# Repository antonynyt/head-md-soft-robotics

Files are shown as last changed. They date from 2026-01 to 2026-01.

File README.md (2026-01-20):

# Pulmo

**Pulmo** is a speculative robot inspired by sea slugs and bioluminescent marine life. It performs slow, breathing-like movements. As air pollution increases, Pulmo’s breathing becomes rapid. Its skin shifts to red as a warning signal. In clean air, its breathing is slow and its body emits a blue-green glow. Pulmo makes air pollution visible and emotionally perceptible.

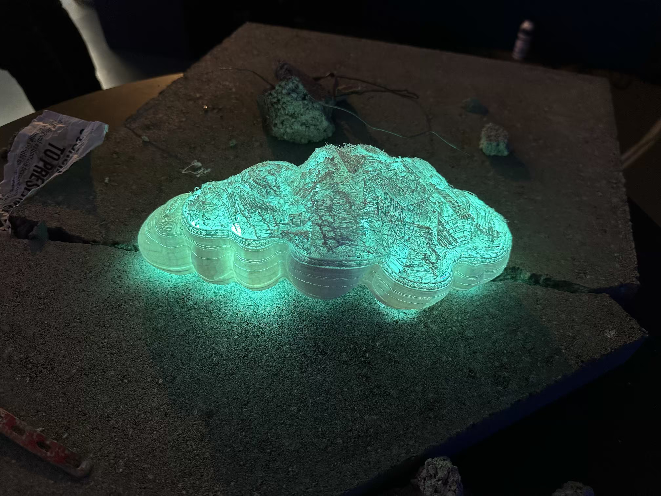
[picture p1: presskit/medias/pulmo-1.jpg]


Pulmo is part of a fictional group of robots created by the last humans before all living beings on Earth had disappeared. These robots were meant to care for the planet, based on the belief that technology could fix the damage humans had caused. Long after humans are gone, the robots continue their work alone making them useless creatures.

## Components

This project is a mix of Arduino & 3D printing. It uses one servo-motor, a CO2 sensor MQ-135 and LEDs ([see details](code)).

# What’s in this repo

- [process/journal.md](process/journal.md) — Development journal
- [process/](process) — Project process
- [code/](code) — Arduino code & schematics
- [presskit/](presskit) — Abstract and medias about the project

> *Most of our process is written in french.*

## Team
Vincent Paley [@noctoplasma](https://instagram.com/noctoplasma) & Antony Neyret [antony.cool](https://antony.cool/)

# About the workshop — Soft Robotics

Project made during the Soft Robotics workshop in Master Media Design, HEAD – Genève.

- **Partners: CNRS, CEA, INRIA**
- **Professors: Clara Rigaud, Benjamin Gaulon**

As our planet faces accelerating ecological crises, robotics offers new ways of perceiving, sensing, and interacting with the environment. Moving beyond efficiency and automation, this workshop explores soft, ecological, and sensitive robots.

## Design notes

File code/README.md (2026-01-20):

# Components

- Arduino Uno R3
- MQ-135
- LED 20mm [Adafruit](https://www.adafruit.com/product/1547) [docs](https://learn.adafruit.com/20mm-led-pixels?embeds=allow)
- Basic servo-motor

# Wiring
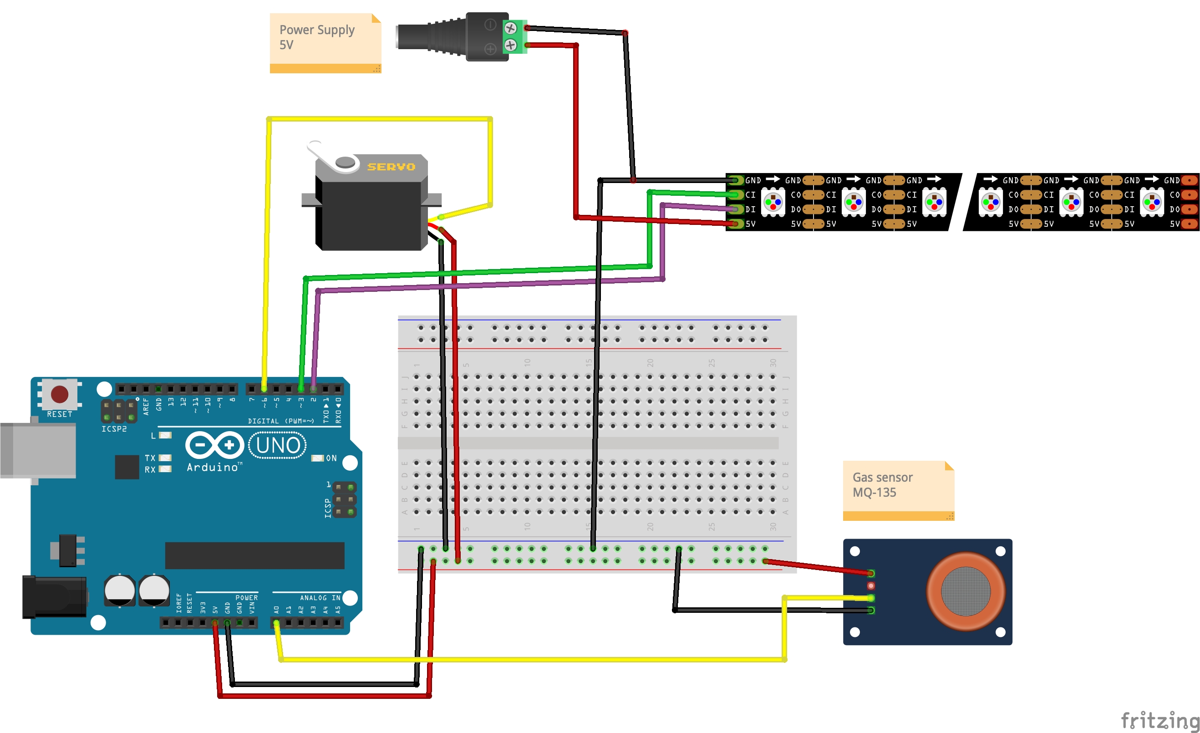
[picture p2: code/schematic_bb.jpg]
[fritzing schematic file](schematic.fzz)

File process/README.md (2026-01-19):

# Process

- [Journal](journal.md)
- [3D Files](3D) - contains `stl` files for 3D printing

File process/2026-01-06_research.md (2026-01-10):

https://www.berndnaut.nl/
bioluminéscence

Télégraphe optique: communication.
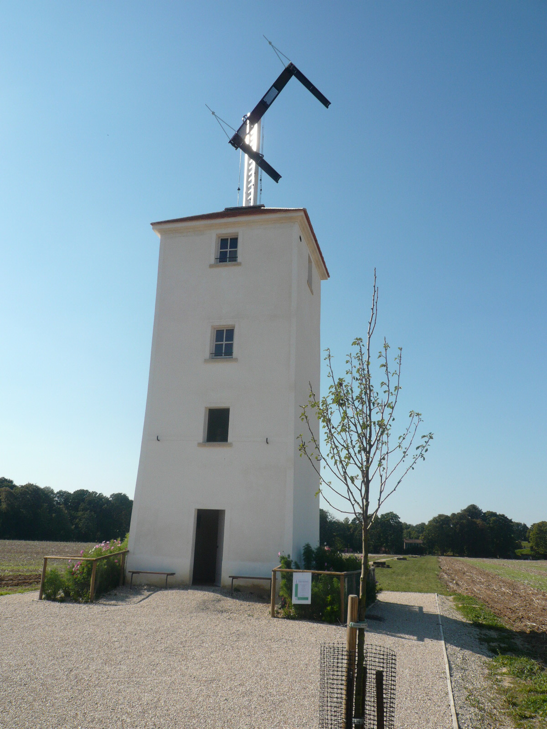
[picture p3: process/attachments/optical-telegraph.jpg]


Mammlus pour la forme jellyfishy
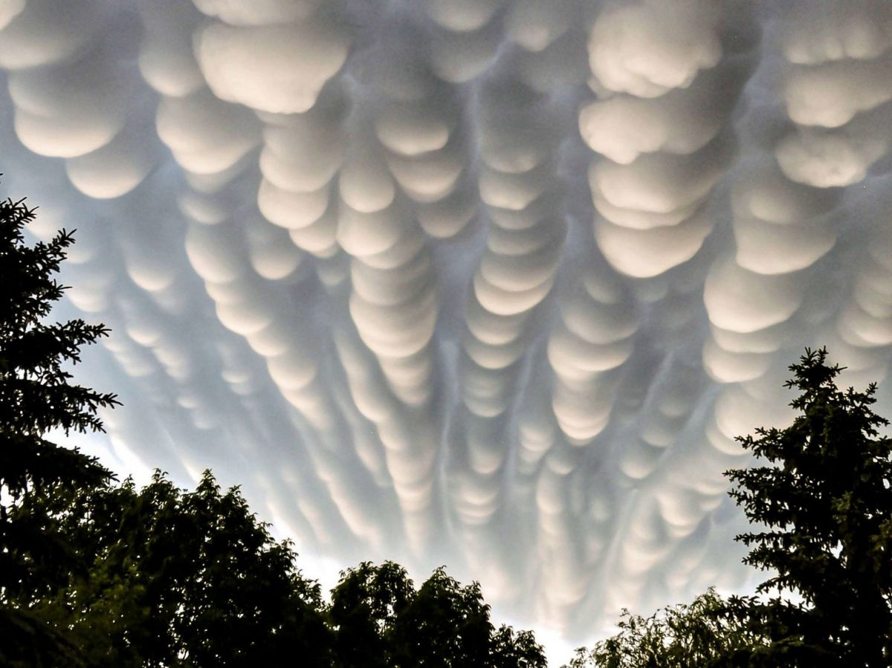
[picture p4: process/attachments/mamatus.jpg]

Omus pour les yeux.
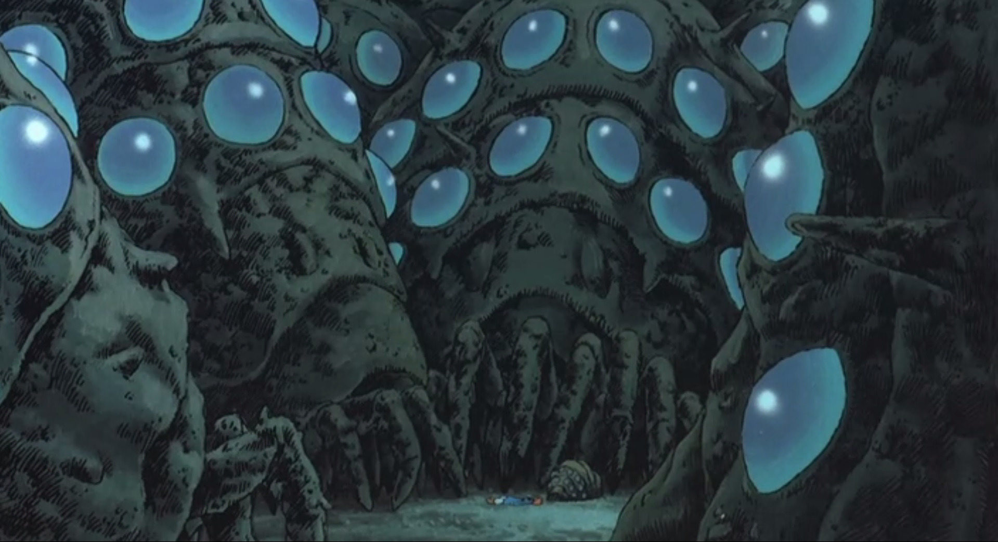
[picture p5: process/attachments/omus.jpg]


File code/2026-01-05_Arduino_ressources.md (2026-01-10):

## Wiki

LED, long leg = +
Diode = one way  -|>-
[Calculer une résistance](https://www.digikey.fr/fr/resources/conversion-calculators/conversion-calculator-resistor-color-code)

## Serial port

[Using the Web Serial API ](https://developer.mozilla.org/en-US/docs/Web/API/Web_Serial_API "https://developer.mozilla.org/en-US/docs/Web/API/Web_Serial_API")
### Sound

https://puredata.info/ -> or max msp, -> create sound
Touch designer
Processing

## 3D - Prototyping

[3D to print dynamic objects](https://news.mit.edu/2025/xstrings-3d-printing-strings-together-dynamic-objects-0318)

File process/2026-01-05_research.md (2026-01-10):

[Seahorse](https://www.youtube.com/watch?v=m7oWvPXz-9c)
[méduses](https://www.arte.tv/fr/videos/120423-000-A/meduses/)
[sponges](https://www.youtube.com/watch?v=pTZ211cIjX8)

# Ideas

inspiré de la fonction des capteurs disponibles.

Air pollution (but [baisse pollution](https://www.rts.ch/meteo/2024/article/impact-paradoxal-de-la-baisse-de-pollution-sur-la-temperature-mondiale-28462833.html))
Air filtering CO2 out.
Water filtering?

Sponge.

Taking care of something makes it evolving.
or a plant controlling you
if you don't take care of it or give it not enough CO2 it shocks you or is evil.

What is the impact on is world ?
Quel est son Umwelt ?

Anémone qui capture: sédentaire
capture l'eau, l'oxygène, co2, transforme, convertir

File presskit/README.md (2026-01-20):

# Pulmo

**Pulmo** is a speculative robot inspired by sea slugs and bioluminescent marine life. It performs slow, breathing-like movements. As air pollution increases, Pulmo’s breathing becomes rapid. Its skin shifts to red as a warning signal. In clean air, its breathing is slow and its body emits a blue-green glow. Pulmo makes air pollution visible and emotionally perceptible. From within its body also escapes a high-pitched, wheezing, almost scream-like noise. As pollution levels rise, this sound intensifies, giving Pulmo a fragile, anxious personality.



Pulmo is part of a fictional group of robots created by the last humans before all living beings on Earth had disappeared. These robots were meant to care for the planet, based on the belief that technology could fix the damage humans had caused. Long after humans are gone, the robots continue their work alone making them useless creatures.

# Process

The project followed an iterative process based on research and experiments. We started with ideas inspired by jellyfish and communication systems, trying to solve many problems at once instead of focusing on one. So, we then shifted to a simpler and more emotional concept. We did field research, took apart old tech, tested light communication and tried different mechanical and 3D-printed prototypes. We learned a lot from mistakes and even got some happy accidents like the 3D TPU printing. This created an **organic, soft, and vulnerable look** for the robot.

# Scenography

|  |  |
| --- | --- |

# References

*Pulmo* is inspired by marine organisms reacting to toxic environments and bioluminescent warning systems.

- **Tobias Bradford – dying mechanical dog**  
- **marine organisms (sea-slugs, jellyfish) when on land**  
- **Bioluminescent sea animals** : Light as a stress signal or defense mechanism
- **Ômu – _Nausicaä of the Valley of the Wind_**  

# Medias

[Link to medias folder](medias) — [Presentation](keynote.pdf)

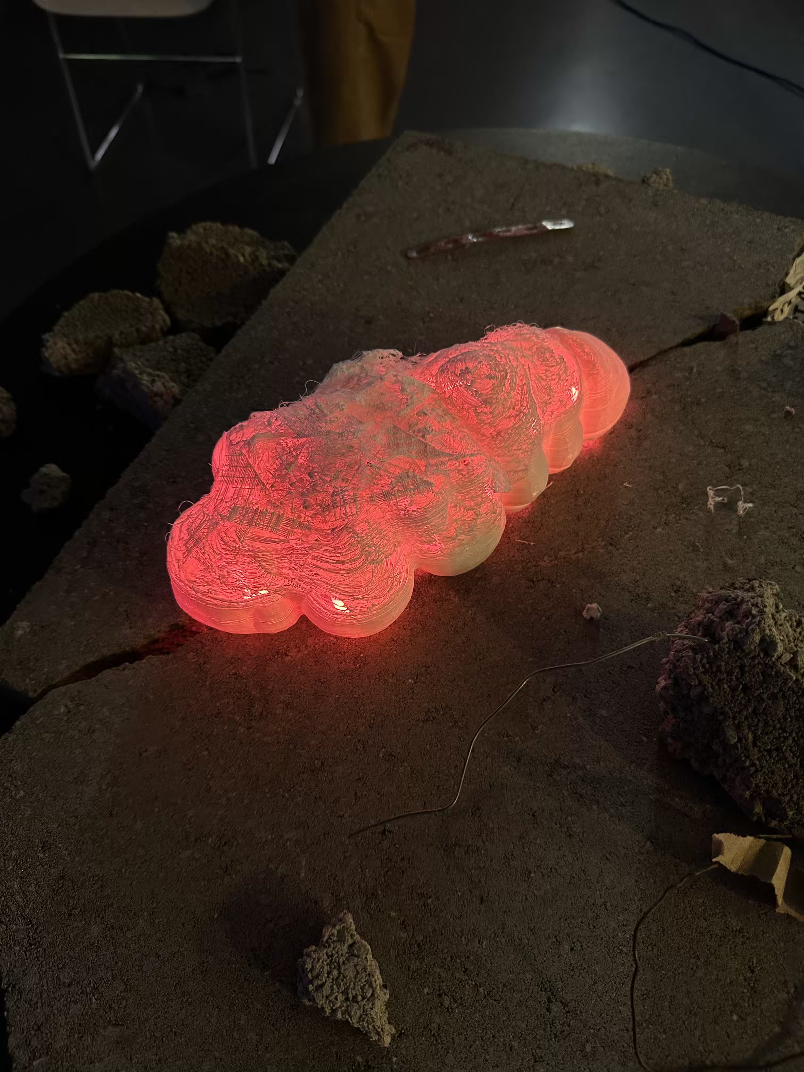
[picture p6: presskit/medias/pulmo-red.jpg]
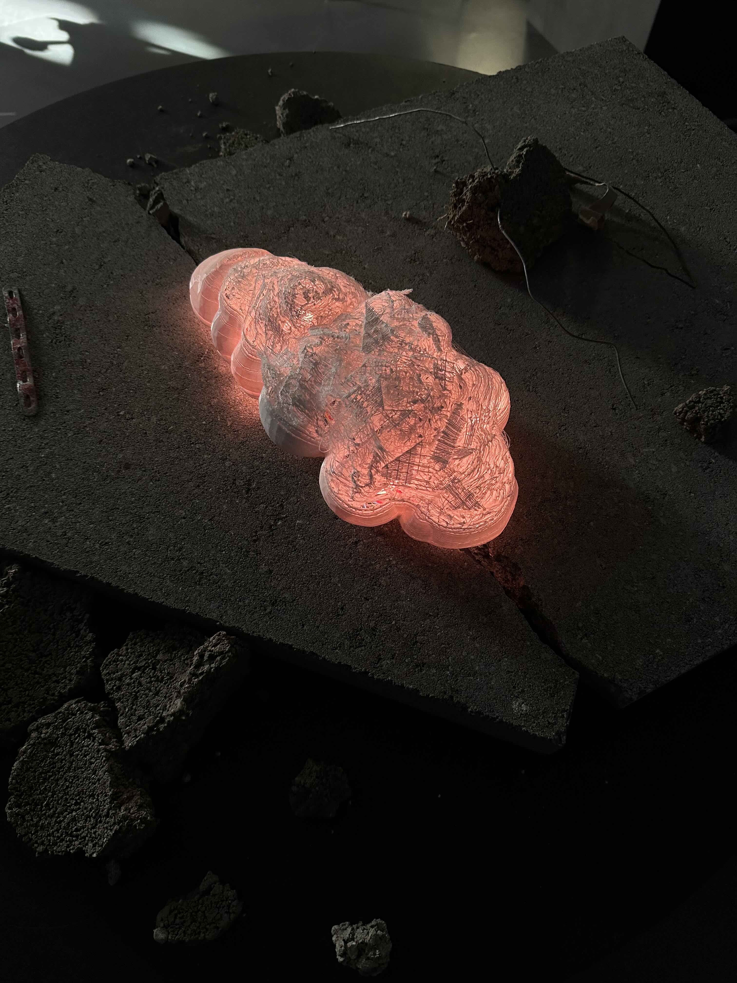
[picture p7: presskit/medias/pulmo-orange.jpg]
|  |  |
| --- | --- |

# Team
Vincent Paley [@noctoplasma](https://instagram.com/noctoplasma) & Antony Neyret [https://antony.cool](https://antony.cool/)

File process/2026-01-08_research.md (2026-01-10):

Humidity sensor (DHT11)
Créer des nuages.
# ideation

**Low tech internet**
Alternative au réseau internet low-tech, auto-sufficient
- mesh-network
## Fonctions
- Savoir comment va l'écosystème ? Permet un état de résonance avec l'environnement.
- Créer de la communication entre humains (connaissance, ).
- Créer de la communication entre autres espèces (laser, radio,)

**What if**
- C'est pas des ondes radios? (eau, brume, lumière, télégraphe optique)
- C'est pas statique?
- ça vole ? -> trop complexe

**Un système de communication qui permet de *résonner* avec l'écosystème.**
Comment ? Pourquoi ?

Le sac ça fait un réseau organique qui est dirigé par les éléments et non par choix.
Un peu comme les animaux marins qui se laissent porter par le vent.
[American Beauty](https://www.dailymotion.com/video/xfy8vo)

## Sac plastique 

Un sac se laisse porter par le vent.

Couleurs des animaux bioluminesents pour camouflage, se cacher des prédateurs humains.
ou alors entrer un message dans l'individu façon: dead-drops ou bouteille à la mer.
Risque de regroupement des sacs tous au même endroit.

Métaphore des déchets de la rue qui voguent: **Fonction d'exploration**: capteur de Co2 urbain mouvant ou détecter les amas de déchets

Pluie de déchets: https://www.youtube.com/watch?v=sdfouAdvav4

Connecté à l'individu: voir l'histoire d'un déchet et se qu'il a vécu.
Lâche un fil, fil d'ariane
Boule western désert.

## Autres idées
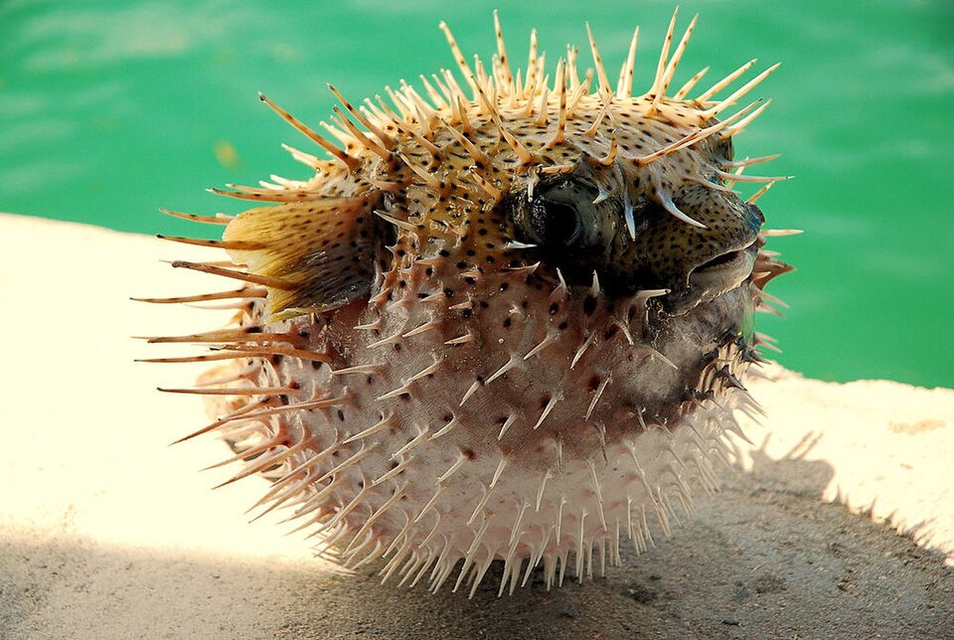
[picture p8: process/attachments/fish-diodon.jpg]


Poisson-hérisson (Diodon)
**Un poisson qui se gonfle comme un ballon en cas de danger.**
- Quel serait ce danger ?

Hippocampe qui s'accroche,
Sauterelle qui saute et plane.

Etoile de mer, qui s'agrippe.
Caméléon.

**--16:43**
Un pont entre l'humain et la nature.
Un pont qui permet de se rendre compte des impact climatiques.
Capteur humidité et CO2.
Cris à l'aide. Buzzer

- define **one precise ecological phenomenon** it translates.
- design **one strong bodily behavior** (instead of many)

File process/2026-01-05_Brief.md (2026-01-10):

HCI human machine interaction
Antropological aspect: what machine that adapt, sense

Maison des humanités potentielles.

what robots wants.
what relationship beyond efficiency.

Marine robotics. the ocean on land
perceving, sensing, interacting with the env.

agents of care and observation

sense humidity, pollution, light
life cycle ecological
fragility, care.
not everything needs to be cute.

Observation des animaux marins.

morphogenesis, 
pattern emerge trough simple chemical processes.

solid <--- viscous --- colloidal --- gel ---> fluid

1. choose non-human reference
2. identify bio mecanisms
3. choose environmental function
4. choose contexte (aquatic, soil, industrial, air, etc.)

filtering -> separate polluants
cleaning -> removing

decompose matter or itself.
plastic operations -> reshape the function, form

1. soft
2. environnemental challenge
3. context
4. function
5. non-human
6. mechanism
7. material
8. operation (plastic)
9. lifecycle
10. interaction
11. energy
12. speculative

it's a proposition not a product.

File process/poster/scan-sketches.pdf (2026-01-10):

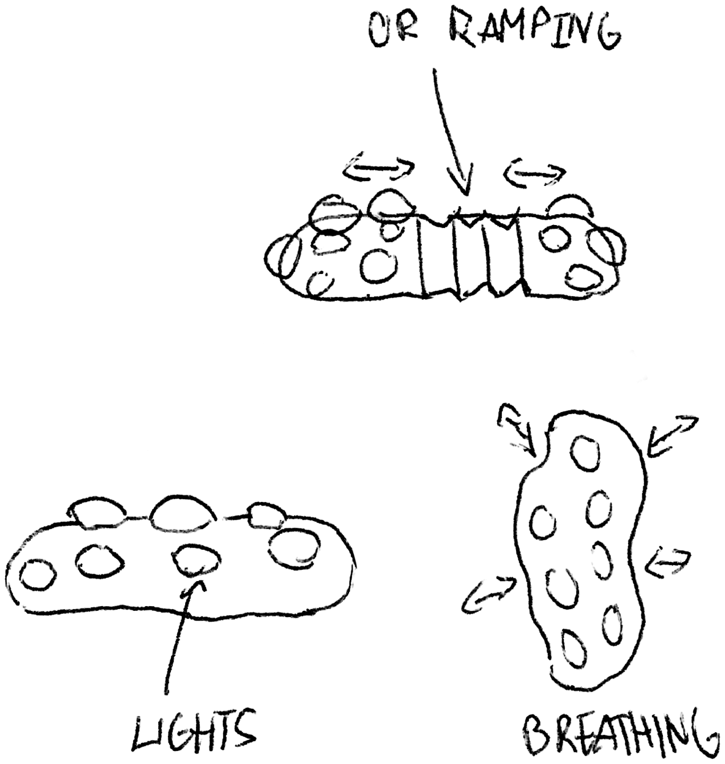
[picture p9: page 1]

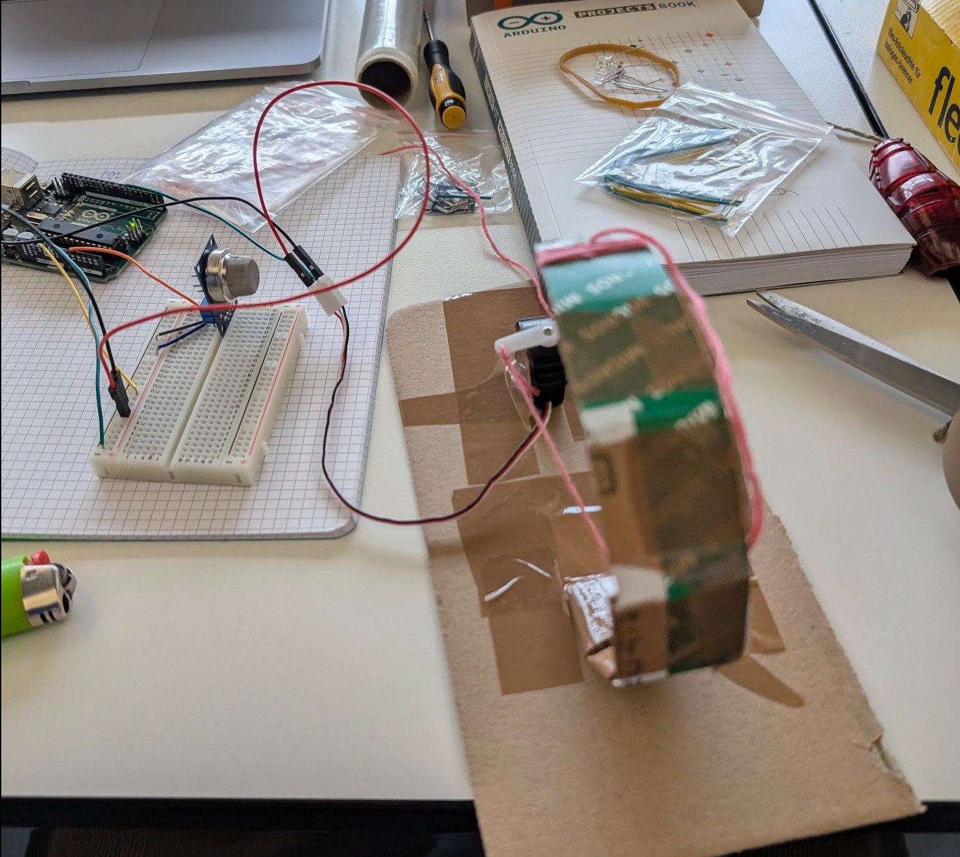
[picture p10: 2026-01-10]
process/attachments/2026-01-09-prototype1.jpg

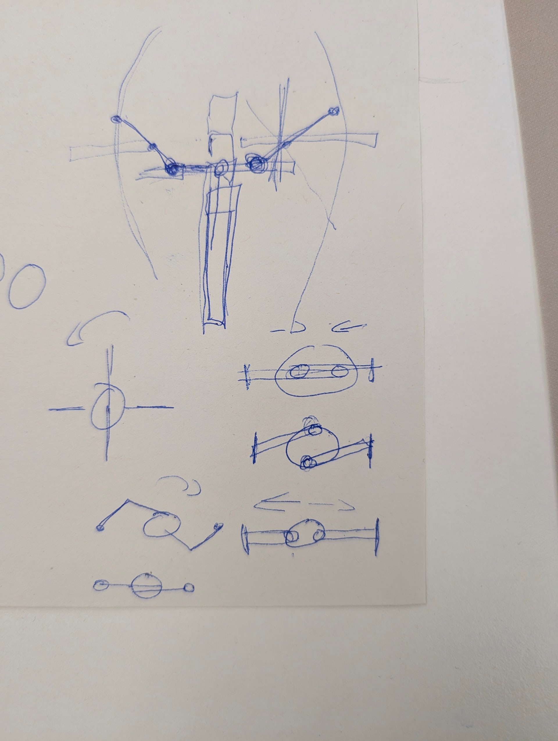
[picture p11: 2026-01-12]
process/attachments/2026-01-12-sketches-mechanism.jpg

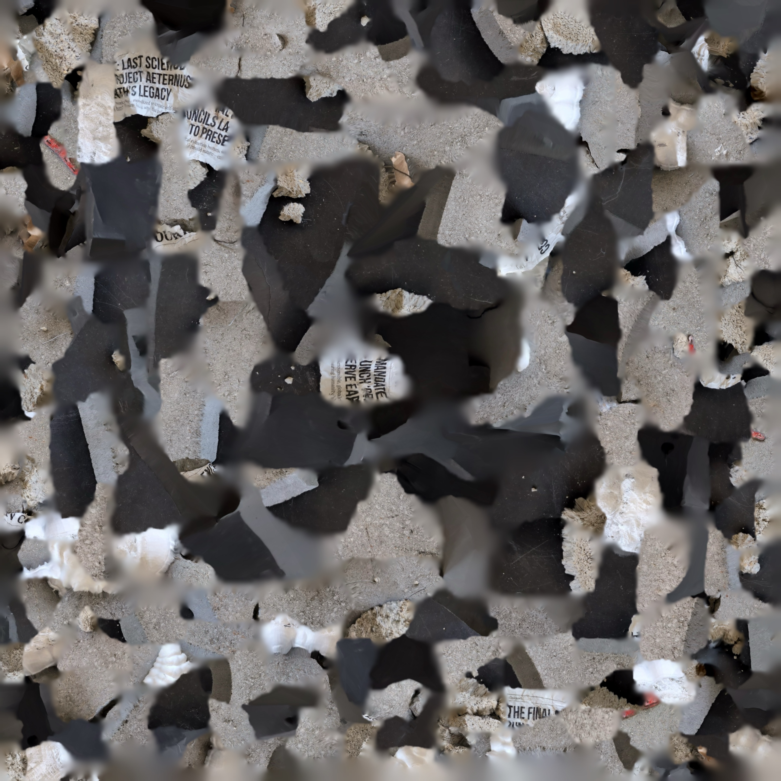
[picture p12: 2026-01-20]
process/3D-scans/lightscan/3DModel.jpg

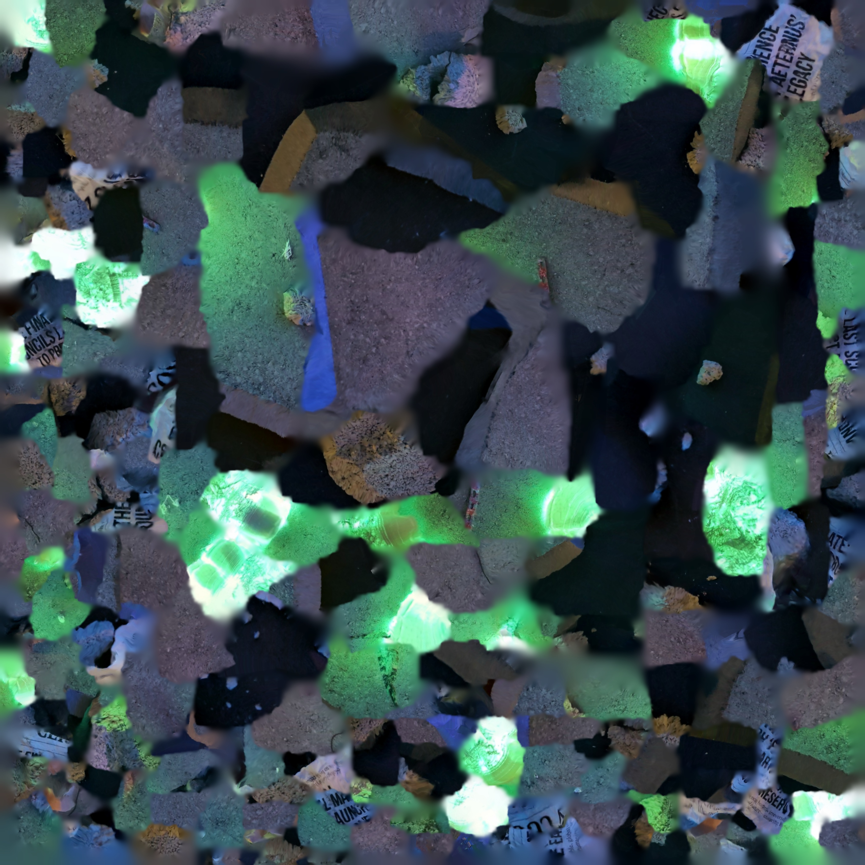
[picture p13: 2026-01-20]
process/3D-scans/darkscan/3DModel.jpg

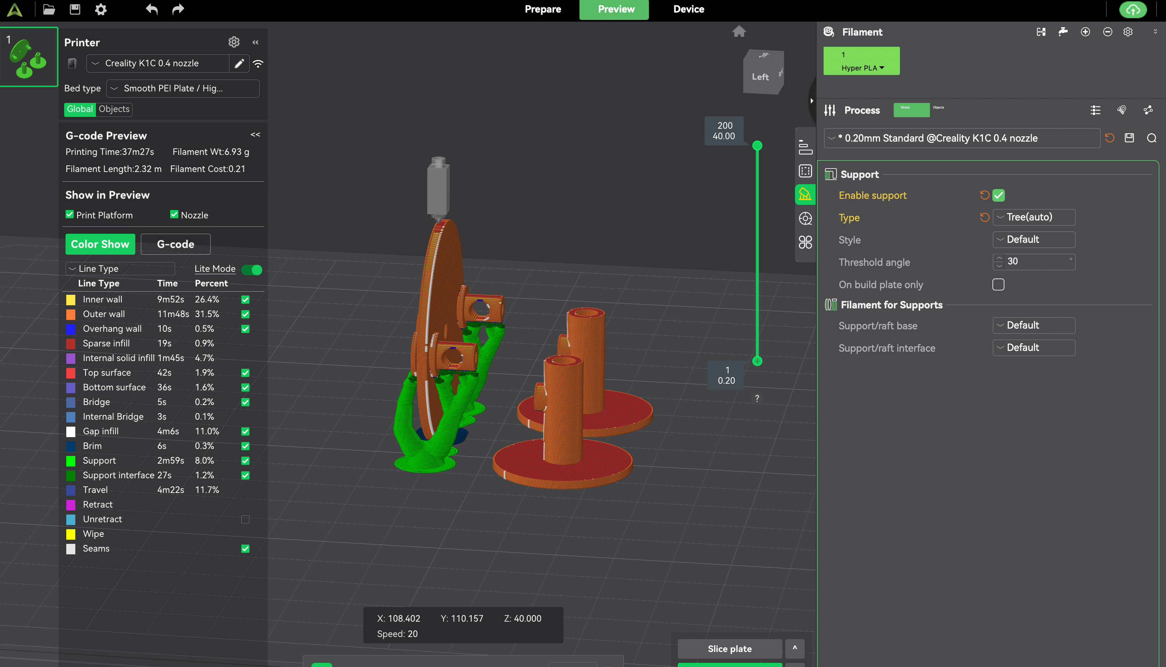
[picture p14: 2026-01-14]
process/attachments/2026-01-13-slicer.jpg

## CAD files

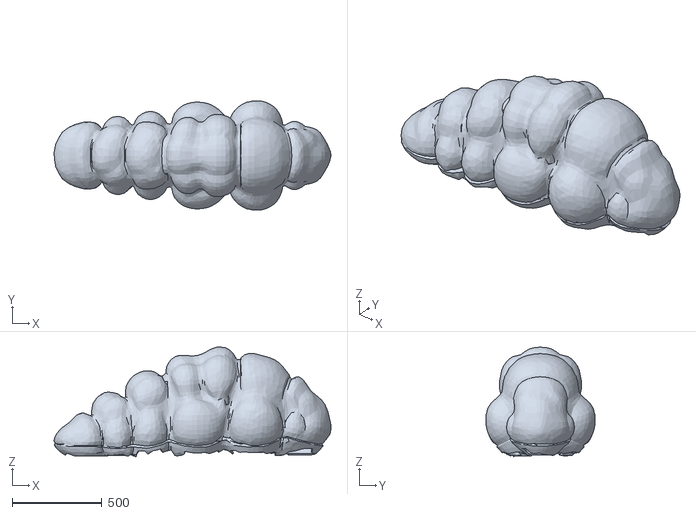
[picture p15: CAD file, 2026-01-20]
process/3D/pulmo/Dying-Robot-final.stl
1540.8 x 608.9 x 610.7

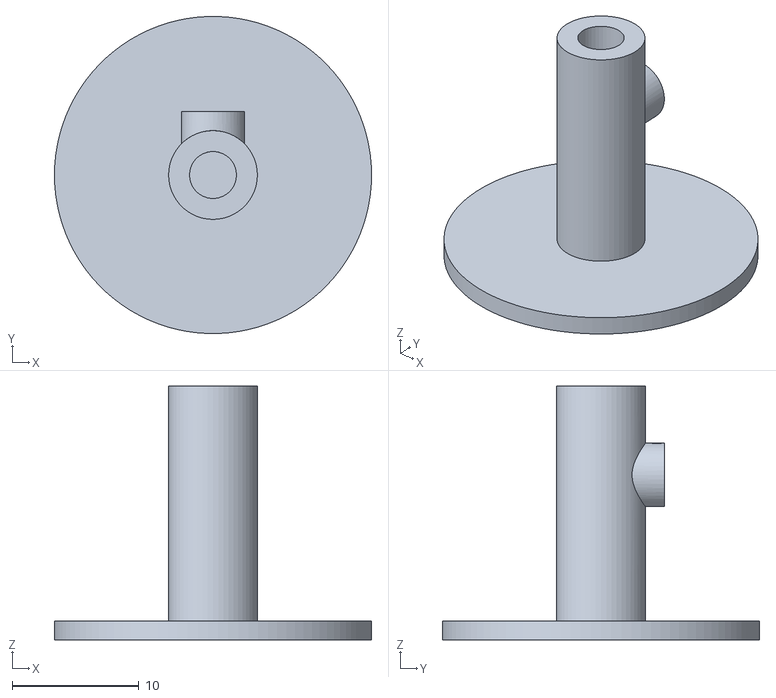
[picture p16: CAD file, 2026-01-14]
process/3D/servo-pushers.stl
25.0 x 25.0 x 20.0

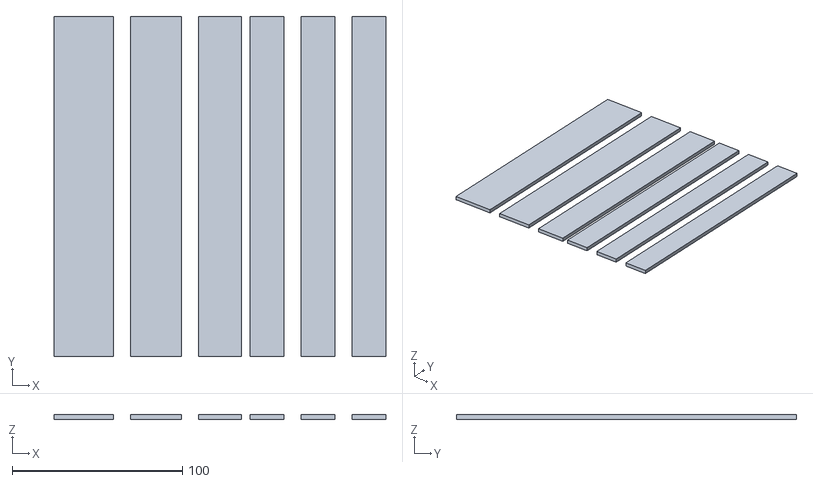
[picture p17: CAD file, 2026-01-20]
process/3D/pulmo/Skeleton.stl
195.0 x 200.0 x 3.00

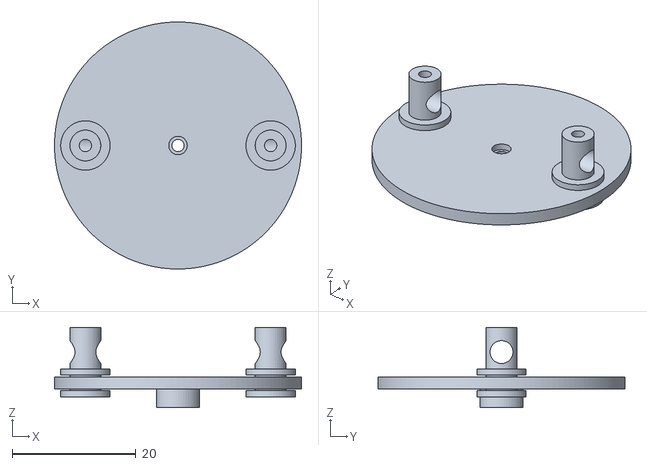
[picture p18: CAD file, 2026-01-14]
process/3D/servo-ring.stl
40.0 x 40.0 x 13.0

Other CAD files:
process/3D/pulmo/Dying-Robot.blend
process/3D/pulmo/Skeleton.f3d
process/3D/servo-pushers.f3d
process/3D/servo-ring.f3d

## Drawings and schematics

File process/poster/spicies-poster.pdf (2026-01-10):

## Side view

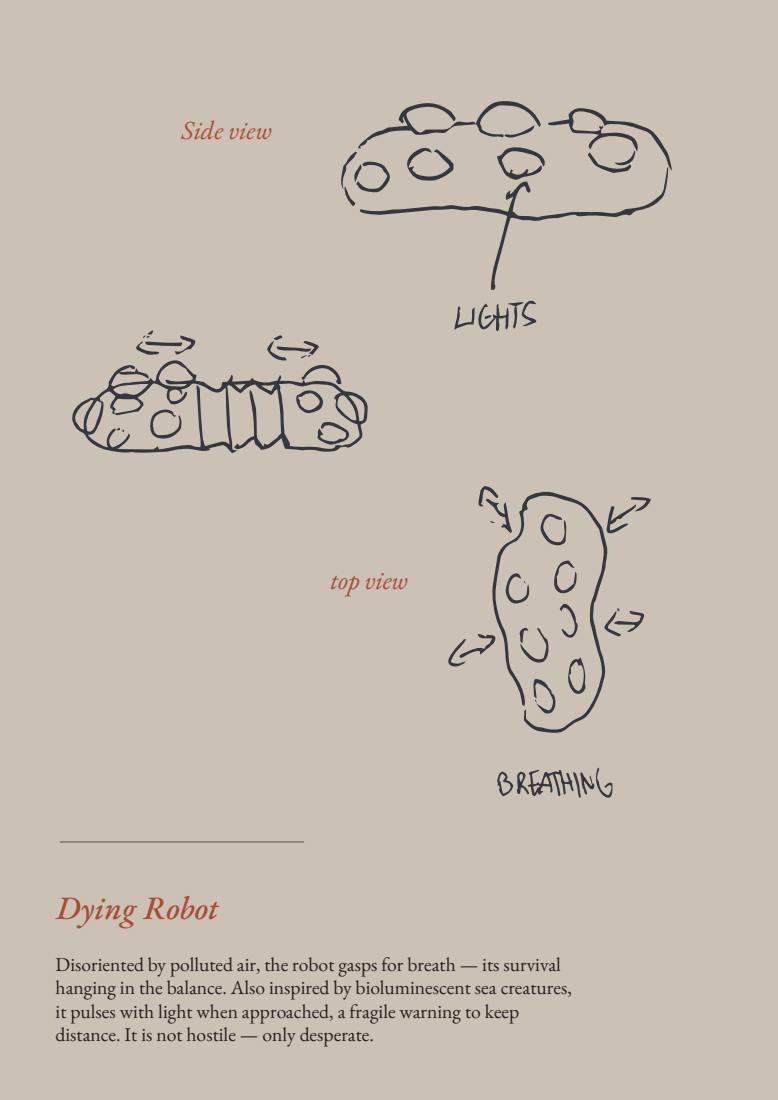
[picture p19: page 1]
Dying Robot; top view

Disoriented by polluted air, the robot gasps for breath — its survival
hanging in the balance. Also inspired by bioluminescent sea creatures,
it pulses with light when approached, a fragile warning to keep
distance. It is not hostile — only desperate.

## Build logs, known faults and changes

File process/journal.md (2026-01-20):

## 2026-01-06

Avec Vincent, on a réfléchit à quelques idées. inspirés de différents objets et animaux marins. À savoir le télégraphe optique pour l'aspect relais de communication via des symboles, les méduses et leurs aspect flottant, les hippocampes ou encore les *Ômu* dans *Nausicaa de la vallée du vent* avec leurs yeux de couleurs rouges et bleus.

Cela donnerait une méduse volante dans les milieux urbains qui régule la répartition de l'eau vers les zones arides. En captant l'humidité de l'air et l'eau de pluie, le robot pourrait redistribuer dans les cultures par exemples. De plus, il s'agirait d'un réseau de plusieurs méduses qui flotteraient et communiqueraient entre elles via des signaux lumineux (télégraphe). Chacune serait un agent autonome dans le réseau.

**Quelques interrogations**: 
pourquoi remplacer la nature? quels sont les risques parado sur l'enviro ?
Comment ça vole ou ça se déplace ?
Comment c'est alimenté ?

## 2026-01-07

Brocante.
Field research et démontage de matériel tech.
Démontage d'un caméscope.

## 2026-01-08

On a encore exploré quelques idées différentes car nous ne sommes pas satisfaits de l'idée de faire voler ou de la méduse. Nous sommes partis sur faire un réseau hors internet, puis d'une carte des déchets qui volent dans la rue. (Voir [2026-01-08_research](2026-01-08_research.md).)

Nous avons fait quelques tests de [code](../code/2026-01-08_morse-code) communication via lumière en envoyant du morse. Peut-être que le binaire serait plus pertinent ? On a aussi tester de faire gonfler du papier ou du tissu avec un ventilateur d'un vieux beamer. Finalement, une autre idée est venue: 

**Badly surviving robot.**
Breathing robot based on air pollution levels (CO2 sensor). The robot struggles to breath. Inspired by bioluminescent sea animals, it flashes when someone is too close to protect itself. It's not really friendly. It is also inspired by the fish that grows when in danger. We are thinking about some mouvement behaviour like it has one leg to move but it's useless or like an accordéon or a worm. But since it's disoriented due to air pollution it's in agony struggling to survive. We will try to make it a bit cute to play with empathy.

#### **Feedback IA Euria:**

- Clarifier le concept : Choisir une seule métaphore forte (ex. : un poisson asphyxié par la pollution, ou un méduse qui clignote quand l’air est toxique).
- Simplifier le mouvement : Utiliser un seul type de mouvement expressif (ex. : pulsation, respiration) plutôt qu’un “accordéon inutile”.
- Renforcer le lien écologique : Lier la pollution de l’air à un impact sur les écosystèmes marins (ex. : acidification des océans due au CO₂).
- Jouer sur l’empathie : Rendre le robot plus “vivant” (ex. : battements de cœur, sons respiratoires) pour créer un lien émotionnel.

## 2026-01-09 — Mid-presentation

Nous avons travaillé sur le dernier concept en date: Le robot qui agonit. Clara nous a montré [une oeuvre](https://www.instagram.com/tobias_bradford/reel/DAOQzbexlxh/) de Tobias Bradford d'un chien mécanique qui meurt et respire mal avec un accordéon.

Pour présenter le concept l'après-midi, nous avons fait une [affiche](poster/spicies-poster.pdf). Vincent a réussi à allumer ses LEDs. Antony a fait un petit [prototype](attachments/2026-01-09-prototype1.jpg) qui à partir d'un composant MQ-2 (capteur de fumée), fait bouger une servo-moteur ([code](code/2026-01-09_breathing-air-servo)).

Nous avons eu quelques feedback notamment sur les matériaux, peut-être imprimer 3D TPU.

## 2026-01-12

On a tester plusieurs prototypes de mécanismes. Antony a réalisé un test de mécanisme en 3D sur [fusion](attachments/2026-01-12-fusion.jpg). Vincent a pu faire des tests d'impression sur le TPU. Ça devrait être assez flexible pour le faire bouger. Et [laisse bien passer la lumière](attachments/2026-01-12-proto-lights-trought.jpg). On tente une impression plus grande. Idéalement, j'aurais apprécié utiliser des matériaux recyclés. Ou le minimal d'impression 3D.

Un discussion avec Pablo a aidé de réfléchir à un [mécanisme](attachments/2026-01-12-sketches-mechanism.jpg) plus simple. A tester demain.

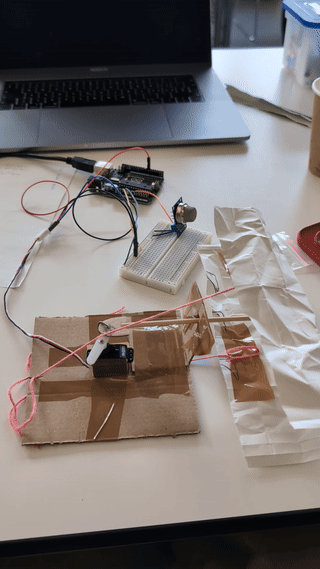
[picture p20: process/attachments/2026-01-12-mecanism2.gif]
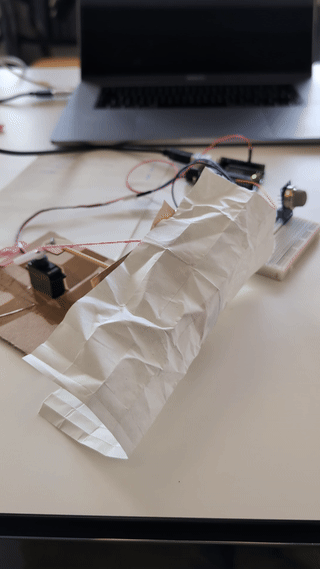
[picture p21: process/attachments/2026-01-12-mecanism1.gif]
|  |  |
| --- | --- |

## 2026-01-13

La 3D TPU n'a pas bien fonctionné mais donne un aspect organique que nous allons garder. Ca rend aussi la bête plus vulnérable.

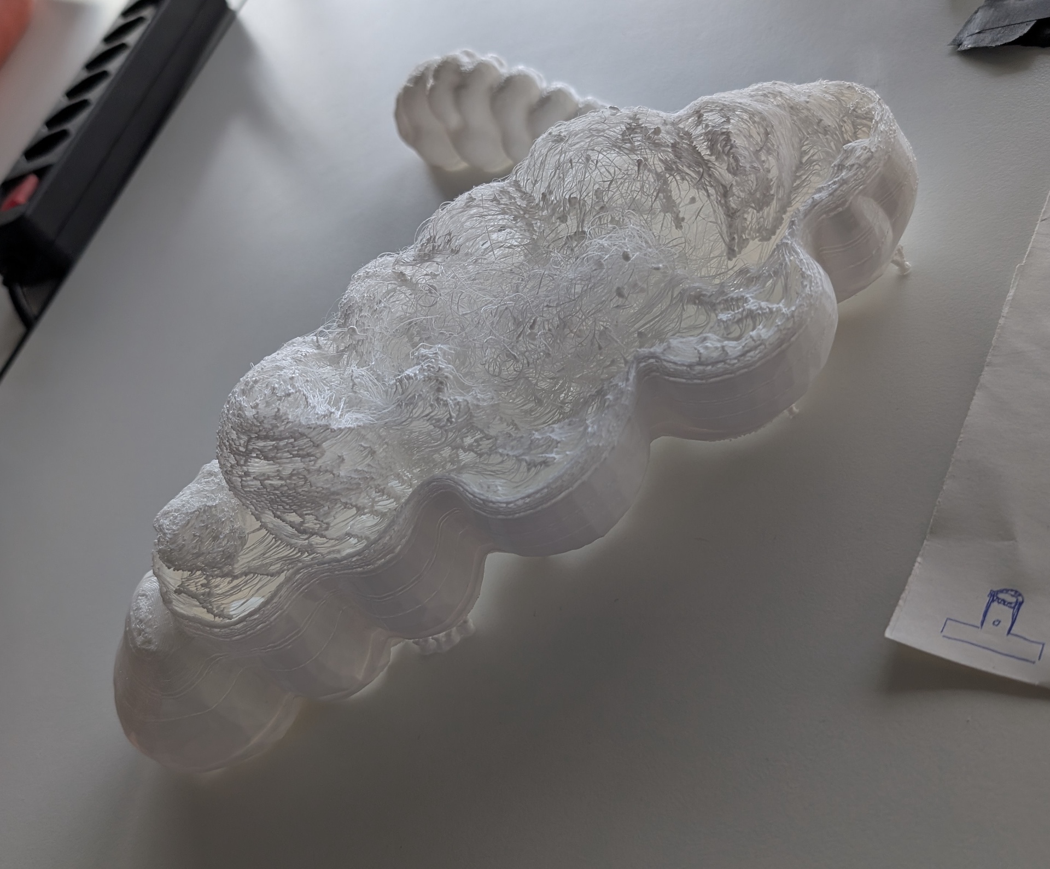
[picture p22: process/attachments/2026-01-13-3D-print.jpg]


Nous avons testé le mécanisme décrit hier. Bien-sûr c'est seulement en fin de journée qu'on a réussi à le faire fonctionner. Le soucis: Le mouvement du servo-moteur doit rester sur un axe droit donc ne pas trop tourner. Sans faire de calculs un mouvement de 70° pour un diamètre de 40mm avec le centre du trou rotation à 4mm du bord du cercle fonctionne bien. De plus, les poussoirs doivent être rattachés au servo-moteur. Des bandes de papier fonctionnent bien.

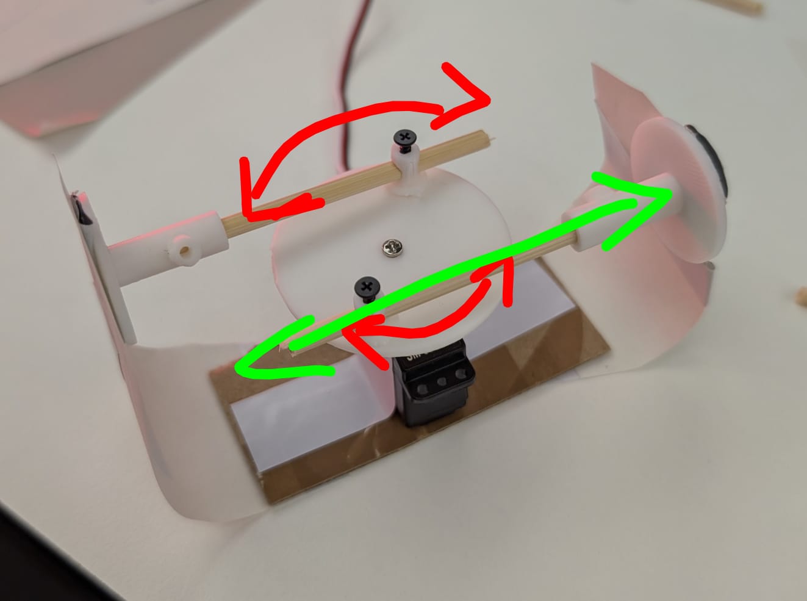
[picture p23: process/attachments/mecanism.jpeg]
|  |  |
| --- | --- |
Pour l'impression 3D, [slicer](attachments/2026-01-13-slicer.jpg) le cercle en vertical.

**Scénario**

Nous avons repensé le scénario. Soit, Il s'agit d'une métaphore. Permet de voir l'invisible. La pollution de l'air n'est pas visible, elle se ressent. Ce robot est passif. Il permet de matérialiser la pollution de l'air. Soit, il s'agit d'un scénario de film de science-fiction.

*Humanity destroyed all living beings on Earth. Before its own extinction, it formed groups of scientists to create a new, self-sustaining ecosystem of robots. Driven by the will to leave a lasting mark on the planet, humans convinced themselves that nature needed their intervention even as they were the cause of its collapse. Robots continues their tasks alone. Humanity’s mark remains even though it is long gone.*

## 2026-01-14

Vincent added some fish-bones like inside the shell to give it more volume and also fix the 3D problem in our favor. We changed the servo to a more powerful one. We had to adapt the 3D printed [circle fixation on the servo](attachments/2026-01-14-mecanism.jpg). It was to fitting anymore. We got new toys from Andrea and a MQ-135 for air quality detection. So now we use it!

The [code](../code/2026-01-14-breathing-light) is now handling the breathing and the color-shiffting from blue-green to red when CO2 or gaz is detected. range from <80 = good, >350 = bad air quality. For testing we use a lighter, butane triggers the system.



Tomorrow we create the scenography and done! :) It lives in urban environment, it's a dangerous place anything can hurt it. But the worse is the air pollution. We still have to find a name. something probably with the fact that is sensing air or alone.

Breathing air pollution (alone).

## 2026-01-15

Préparation de la présentation, mise en place de la scénographie. Réalisation d'une fausse en-tête de journal pour la contextualisation. Aller près des chantier pour récupérer des morceaux de béton et de barres en métal. Did [3D scans](./3D-scans/) of the scenography.

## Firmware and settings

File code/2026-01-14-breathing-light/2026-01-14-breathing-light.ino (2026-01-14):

#include <Servo.h>
#include "SPI.h"
#include "Adafruit_WS2801.h"

Servo myservo;

// ----- PINS -----
uint8_t dataPin  = 2;
uint8_t clockPin = 3;

Adafruit_WS2801 strip = Adafruit_WS2801((uint16_t)7, (uint16_t)7, dataPin, clockPin);

// ----- SERVO -----
#define DEVIATION 40
int START_ANGLE = 20 + DEVIATION;
int END_ANGLE   = 60 + DEVIATION;

int pos = START_ANGLE;
int direction = 1;

// ----- TIMING -----
unsigned long lastServoUpdate = 0;
unsigned long lastLedUpdate   = 0;

// ----- SPEED -----
int speedMs = 20;   // updated from potentiometer

float dangerSmoothed = 0.0;

void setup() {
  pinMode(A0, INPUT);
  myservo.attach(6);

  strip.begin();
  strip.show(); // lights off

  Serial.begin(9600);
}

void loop() {
  // Read air (A0)
  int airQuality = analogRead(A0);

  Serial.println(analogRead(A0));
  speedMs = map(airQuality, 80, 350, 20, 5);
  speedMs = constrain(speedMs, 5, 20);
  

  updateBreathingLEDs();
  updateServo();
}

// ================= SERVO (non-blocking) =================
void updateServo() {
  unsigned long now = millis();

  if (now - lastServoUpdate >= speedMs) {
    lastServoUpdate = now;

    pos += direction;

    if (pos >= END_ANGLE || pos <= START_ANGLE) {
      direction *= -1;
    }

    myservo.write(pos);
  }
}

// Base colors (no brightness applied)
const float BASE_GREEN_R = 0.1;
const float BASE_GREEN_G = 0.5;
const float BASE_GREEN_B = 0.1;

const float BASE_RED_R   = 0.6;
const float BASE_RED_G   = 0.05;
const float BASE_RED_B   = 0.02;


// ================= LED WITH EASING =================
void updateBreathingLEDs() {
  unsigned long now = millis();

  if (now - lastLedUpdate >= speedMs) {
    lastLedUpdate = now;

    // -------- Servo easing --------
    float t = (float)(pos - START_ANGLE) / (float)(END_ANGLE - START_ANGLE);
    t = constrain(t, 0.0, 1.0);
    float eased = easeInOut(t);

    uint8_t brightness = (uint8_t)(
      255 + eased * (80 - 255)
    );
    brightness = constrain(brightness, 60, 255);

    // -------- Danger smoothing --------
    float dangerTarget = (float)(20 - speedMs) / (20 - 10);
    dangerTarget = constrain(dangerTarget, 0.0, 1.0);

    dangerSmoothed += (dangerTarget - dangerSmoothed) * 0.08;
    float danger = easeInOut(dangerSmoothed);

    // -------- Color blend (NO brightness yet) --------
    float r = BASE_GREEN_R + danger * (BASE_RED_R - BASE_GREEN_R);
    float g = BASE_GREEN_G + danger * (BASE_RED_G - BASE_GREEN_G);
    float b = BASE_GREEN_B + danger * (BASE_RED_B - BASE_GREEN_B);

    // -------- Apply brightness ONCE --------
    uint8_t R = r * brightness;
    uint8_t G = g * brightness;
    uint8_t B = b * brightness;

    uint32_t color = Color(R, G, B);

    for (int i = 13; i < strip.numPixels(); i++) {
      strip.setPixelColor(i, color);
    }
    strip.show();
  }
}



// ================= HELPERS =================
uint32_t Color(byte r, byte g, byte b) {
  uint32_t c;
  c = r;
  c <<= 8;
  c |= g;
  c <<= 8;
  c |= b;
  return c;
}

float easeInOut(float t) {
  // t must be between 0.0 and 1.0
  return t * t * (3 - 2 * t);
}

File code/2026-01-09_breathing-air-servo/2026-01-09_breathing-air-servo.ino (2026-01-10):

#include <Servo.h>

Servo myservo;
int pos = 0;

void setup() {
  // put your setup code here, to run once:
  pinMode(0, INPUT);
  myservo.attach(6);
  Serial.begin(9600);

}

void loop() {
  // put your main code here, to run repeatedly:

  if (analogRead(0) > 200) {
    myservo.write(180);
    
  } else {
    for (pos = 10; pos <=50; pos++) {
      myservo.write(pos);
      delay(15);
    }
    for (pos = 50; pos >=10; pos--) {
      myservo.write(pos);
      delay(15);
    }
  }

  Serial.println(analogRead(0));

  delay(5);

}

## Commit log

2026-01-14 update today & yesterday journal
    [servo-pushers.stl, servo-ring.stl]
2026-01-20 add schematics
    [schematic.fzz]
2026-01-20 update schematics to jpg
    [schematic.fzz]
2026-01-20 add 3d print files
    [Dying-Robot-final.stl, Dying-Robot.blend, Skeleton.f3d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]
